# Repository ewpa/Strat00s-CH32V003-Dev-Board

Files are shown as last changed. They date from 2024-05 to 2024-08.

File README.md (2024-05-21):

# CH32V003-Dev-Board
<p float="left">
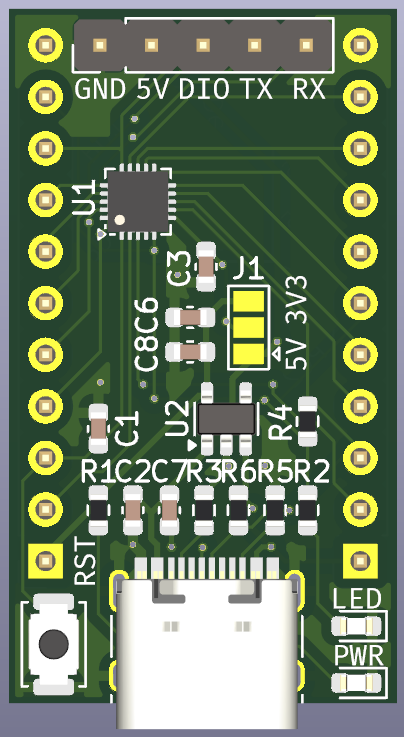
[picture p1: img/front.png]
  
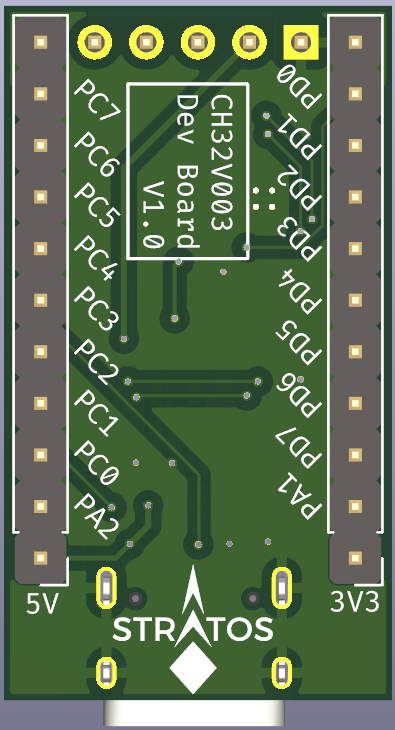
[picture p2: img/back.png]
  
</p>

A minimal CH32V003F4U6 based dev board for playing with the CH32V003 MCU.

The board should have everything required to get the chip working, together with a ME6211C33M5 3v LDO. The LDO is not required and can be ommited, but LEDs won't work as they are powered from it. The 3V and 5V rails can be joined together to power them again. USB is wired to hopefully support [RV003USB](https://github.com/cnlohr/rv003usb) bootloader.

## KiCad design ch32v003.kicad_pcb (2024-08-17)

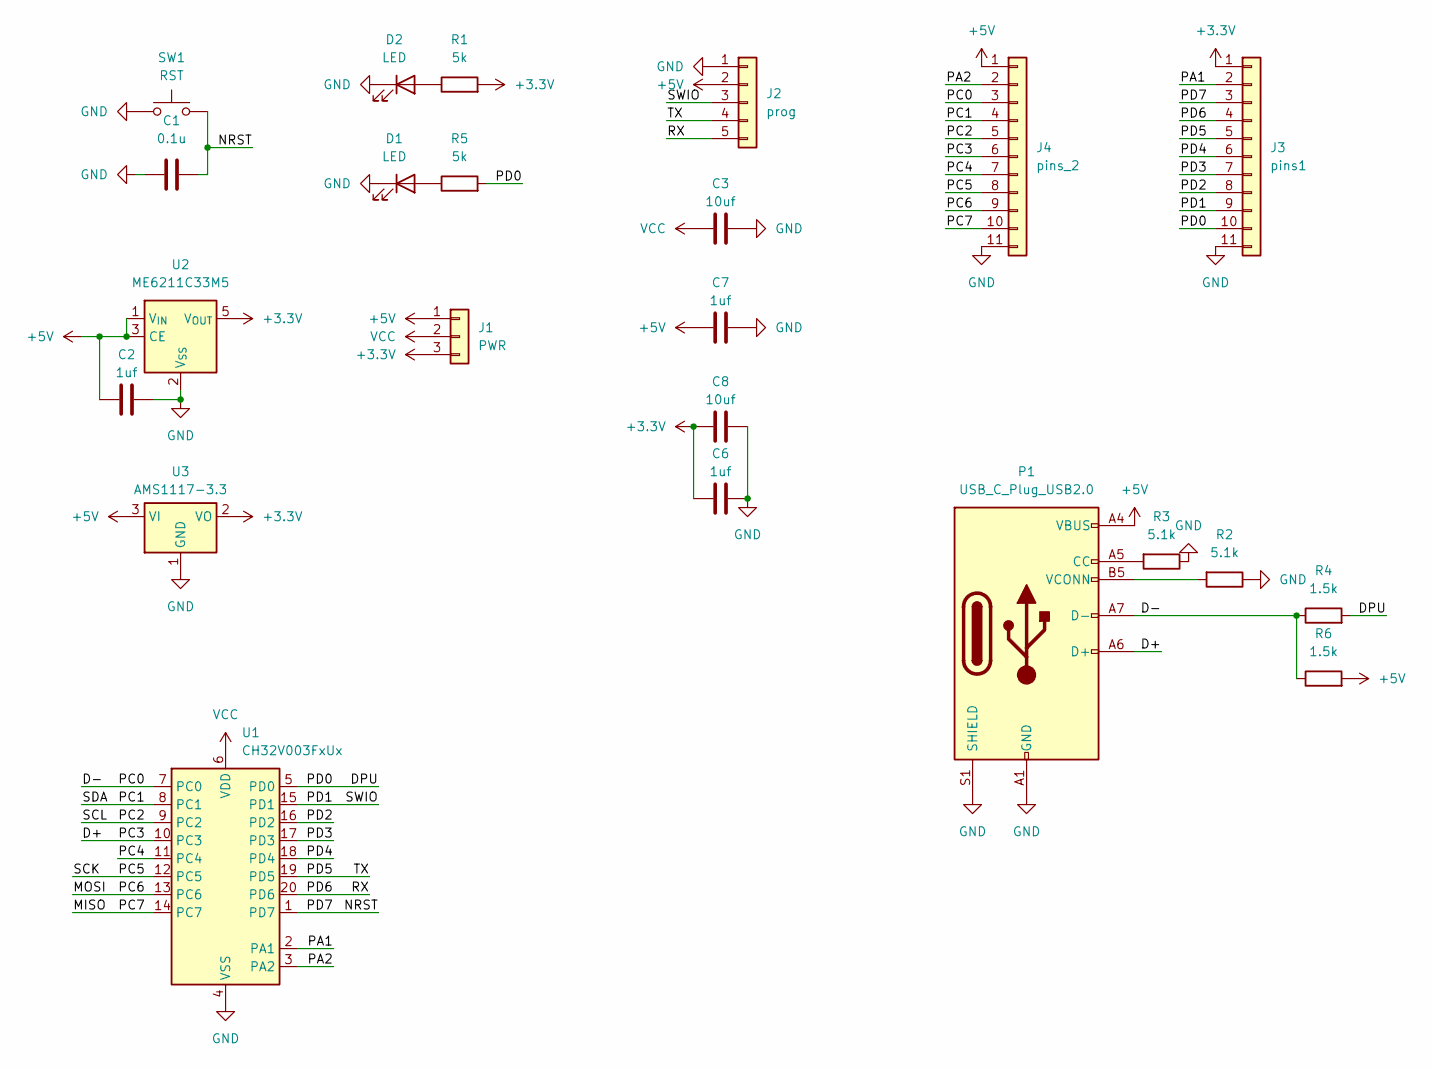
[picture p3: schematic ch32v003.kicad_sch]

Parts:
C1: 0.1u; C_0603_1608Metric
C2, C6, C7: 1uf; C_0603_1608Metric
C3, C8: 10uf; C_0603_1608Metric
D1, D2: LED; LED_0603_1608Metric
J1: PWR; SolderJumper-3_P1.3mm_Open_Pad1.0x1.5mm
J2: prog; PinHeader_1x05_P2.54mm_Vertical
J3: pins1; PinHeader_1x11_P2.54mm_Vertical
J4: pins_2; PinHeader_1x11_P2.54mm_Vertical
P1: USB_C_Plug_USB2.0; USB_C_Receptacle_HRO_TYPE-C-31-M-12
R1, R5: 5k; R_0603_1608Metric
R2, R3: 5.1k; R_0603_1608Metric
R4, R6: 1.5k; R_0603_1608Metric
SW1: RST; SW_Push_SPST_NO_Alps_SKRK
U1: CH32V003FxUx; QFN-20-1EP_3x3mm_P0.4mm_EP1.65x1.65mm
U2: ME6211C33M5; SOT-23-5
U3: AMS1117-3.3; SOT-223-3_TabPin2

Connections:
+3.3V: C6.1, C8.1, J1.3, J3.1, R1.2, U2.5 (V_{OUT}), U3.2 (VO)
+5V: C2.1, C7.1, J1.1, J2.2, J4.1, P1.A4 (VBUS), P1.A9 (VBUS), P1.B4 (VBUS), P1.B9 (VBUS), R6.2, U2.1 (V_{IN}), U2.3 (CE), U3.3 (VI)
/D+: J4.6, P1.A6 (D+), U1.10 (PC3)
/D-: J4.3, P1.A7 (D-), R4.1, R6.1, U1.7 (PC0)
/DPU: J3.10, R4.2, R5.2, U1.5 (PD0)
/MISO: J4.10, U1.14 (PC7)
/MOSI: J4.9, U1.13 (PC6)
/NRST: C1.2, J3.3, SW1.2, U1.1 (PD7)
/PA1: J3.2, U1.2 (PA1)
/PA2: J4.2, U1.3 (PA2)
/PC1: J4.4, U1.8 (PC1)
/PC2: J4.5, U1.9 (PC2)
/PC4: J4.7, U1.11 (PC4)
/PC5: J4.8, U1.12 (PC5)
/PD1: J2.3, J3.9, U1.15 (PD1)
/PD2: J3.8, U1.16 (PD2)
/PD3: J3.7, U1.17 (PD3)
/PD4: J3.6, U1.18 (PD4)
/PD5: J2.4, J3.5, U1.19 (PD5)
/PD6: J2.5, J3.4, U1.20 (PD6)
GND: C1.1, C2.2, C3.2, C6.2, C7.2, C8.2, D1.1 (K), D2.1 (K), J2.1, J3.11, J4.11, P1.A1 (GND), P1.A12 (GND), P1.B1 (GND), P1.B12 (GND), P1.S1 (SHIELD), R2.1, R3.1, SW1.1, U1.4 (VSS), U1.21 (VSS), U2.2 (V_{SS}), U3.1 (GND)
unnamed: D1.2 (A), R5.1
unnamed: D2.2 (A), R1.1
unnamed: P1.A5 (CC), R3.2
unnamed: P1.B5 (VCONN), R2.2
VCC: C3.1, J1.2, U1.6 (VDD)

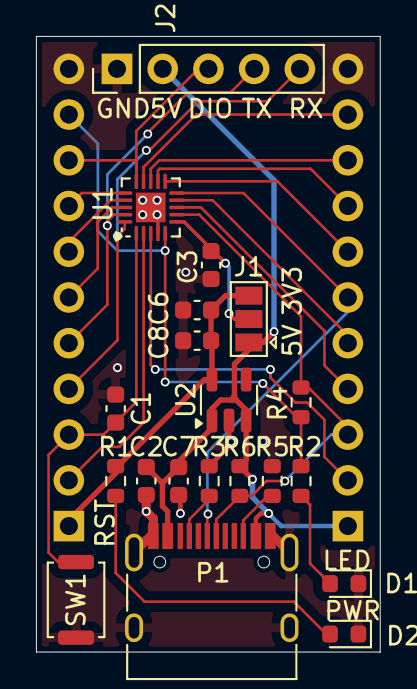
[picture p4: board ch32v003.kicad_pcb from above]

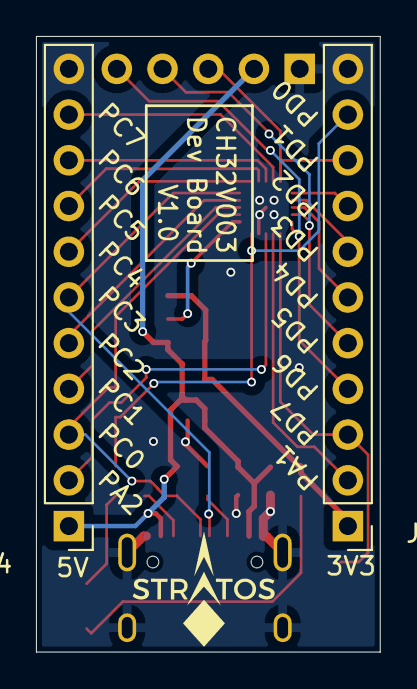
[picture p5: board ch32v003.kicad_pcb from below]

Board: 2 copper layers, 19.1 x 34.2 mm, 22 parts (2 on the bottom side), 26 nets.

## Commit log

2024-05-21 Add missing 3d models
    [ch32v003.kicad_pcb]
2024-05-21 board renders
2024-08-17 Change missing typeface.
    [ch32v003.kicad_pcb]
2024-08-17 Tidy up fabrication layer.
    [ch32v003.kicad_pcb]
